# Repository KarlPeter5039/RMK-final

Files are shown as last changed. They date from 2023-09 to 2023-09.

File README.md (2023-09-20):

# RMK-final
Final iteration of the Reconfigurable Mechanical Keyboard including firmware and PCB files

Developed at Lehigh University for ECE 258 by Sumin Lim '23 and Karl Peter '23

Final PCB render

# Abstract
This project aims to explore new and innovative approaches to keyboard design, with a focus on improving user experience by integrating a modular configuration that can be flexible with user needs. The report begins by introducing our initial design, functionality, and how it improves. Communication between modules is made possible by I2C via TRRS jacks. The report then discusses the development process of this project. This includes hardware and software specifications, ethical aspects, altercations that were made, and discussion of the final design. The last section of this report explores future work or adjustments that could be made to further enhance this project. Overall, this project report demonstrates the value of innovative approaches to keyboard design and highlights the potential for future developments in this field.

Function Block Diagram

# Introduction
Anyone can go out and buy a keyboard, but most are fixed designs/sizes and lack functions that are desirable to those who need them. With a modular configuration, a reconfigurable keyboard is all-in-one and can scale up or down, depending on the task, at any time. This is achieved through a magnetic connection with detachable data pins between modules. The final project will include the following modules: left hand master, right hand, number row, function row, analog knob input cluster, slide potentiometer cluster, arrow key cluster with OLED display, and the number pad.

While there have been many designs for modular keyboards, nothing out there really comes close to the practicality of our design. It will be different from generic commercial designs by adding additional peripherals including rotary encoders for analog input, a fully modular set up, and dedicated keyboard portions that can be connected and disconnected at any time. 

Breakdown of inputs/outputs

# Technical Specifications
## Hardware Specifications:
- Elite-C Microcontrollers - ATmega32U4-based processor at 16MHz with 32KB of flash storage, 26 GPIO pins, and tactile reset button
- Diodes - To prevent back-currents in the keyboard matrix
- TRRS jacks - For I2C connection of modules carrying 4 wires
- Pull-up resistors - 4.7k ohm connected from VCC to SDA and SCL for I2C
- 128X32 OLED screen - Display for words per minute count and bongo cat
- Switches - Digital Cherry MX-based Switches
- Slide Potentiometer - Analog slide input for relative positioning input
- Rotary Encoders - Analog rotating potentiometer inputs for absolute positioning input
- Keyboard plate - 3D printed to mechanically support switches
- PCBs - Designed in KiCAD and ordered from JLCPCB

## Firmware Specifications:
The firmware for a keyboard consists of four primary files: 
- keymap.c: Defines the key mapping of the keyboard
- config.h: Defines the low-level configuration for the keyboard
- rules.mk: Defines the parameters of the ATMega32u4 controller 
- info.json: Defines the physical keyboard layout visually in JavaScript

QMK Firmware was used to configure the keymap, matrix with corresponding rows and columns, and assign keycodes for each of the switches on the keyboard. These files were then flashed to the microcontroller's memory.

### Required software
- QMK MSYS to compile the .c, .h, .mk. and .json files into a single hex file
- QMK Toolbox to flash the compiled hex file to the microcontroller over USB (lots of good tutorials on this)

PCB Schematic view

On the Arduino Pro Micro/Elite-C, I2C is supported through pins PD1, PD0, GND, and VCC (additional pull-up resistors were required). This connection can be achieved through two 4-pin TRRS jacks with a 3.5mm cable. Most of I2C communication lies in the keyboard firmware in the keymap file (.c), config header file (.h), and the rules file (.mk). The left hand module can function on its own, but without it, the rest of the modules would fail to operate.

Final PCB design

# Future Work
We chose to take a simplified approach to our original project plan due to potential hardware address limitations in QMK for 8 modules. We concluded that it would be better to have a couple working modules as opposed to 8 non-working ones. For our final keyboard, we cut the modules to just a left and right half but still included an OLED screen, digital switches, slide potentiometer, and rotary encoders. For future works, this keyboard can potentially expand to our initial goal of the 8 modules specified.

Additionally, to manufacture this keyboard on a larger scale, we have the following design altercations in mind: Breaking away from the Breakout Board, ISP (In-System Programming), Independent Molex/USB/Aviator connection, and LED indicators for boot status/flashing.

### Breaking away from the Breakout Board: 
It is far easier and cheaper to mass produce the PCB without the Arduino/Elite-C breakout boards that house the ATMega32U4 microprocessor. SMD components would be used with an on-board clock at 16MHz, capacitors for phase inversion, and bypass capacitors between Vcc and GND to reduce switching noise.

### ISP (In-System Programming): 
This allows quick flashing of the device with firmware without a direct USB connection. This is ideal in a factory environment where it’s impractical to plug each freshly soldered PCB with a USB connection. Instead, a 6 pin ISP connection will be mounted on the board for device access.
Independent Molex/USB/Aviator connection: This is required when eliminating the breakout board. D+ and D- data connections will be soldered to the connectors to further streamline production and reduce costs at a larger scale.

### LED indicators for boot status/flashing: 
A two LED setup will be used for when the keyboard’s memory is being wiped and when the keyboard is successfully and continuously connected with no errors. This will add two additional resistors for each LED.

Flashing the device

# Building your own RMK

## Bill of Materials (BOM)
| Component Name | Quantity |
| :---: |  :----:  |
| Elite-C Microcontrollers| 2x |
| 1N4148 Diodes | 63x |
| TRRS PJ-320A jacks | 2x |
| 4.7k resistors | 2x |
| 128x32 OLED screen | 1x | 
| 10k Slide Potentiometer | 1x |
| EC11 Rotary Encoders | 3x |
| Mechanical Switches | 63x |
| Left Keyboard Plate | 1x |
| Right Keyboard Plate | 1x |
| Keyboard PCB | 1x |

To order and build your own RMK, you'll have to source the above components on your own. Good keyboard part vendors include [Keebio](https://keeb.io/), [Aliexpress](https://www.aliexpress.com/), [DigiKey](https://www.digikey.com/), [Little Keyboards](https://www.littlekeyboards.com/), [Custom KBD](https://customkbd.com/), and [Amazon](https://www.amazon.com/ref=nav_logo).
Here, you can obtain most common items such as diodes, microcontrollers, TRRS jacks, and more.

For the PCB, download the PCB gerber and drill files from the repository and upload them to [JLCPCB](https://jlcpcb.com/) and order the 2-layer PCB (minimum order quantity should be around ~5 PCBs. Keyboard plates can be designed by hand or 3D printed if you're fancy.

To build the keyboard: a good approach is to first flash the microcontrollers with firmware to test their functionality and return them if they do not work. After that, solder components while periodically testing the board for functionality (shorting key pins with diodes, turning the rotary encoders, sliding the analog slider, etc.). Hopefully, after some sweat and hopefully no tears, you'll have your own working RMK! Firmware can additionally be customized to your liking by editting the various provided files and compiling them using QMK MSYS + flashing with QMK Toolbox. 

Customization includes 
- Custom keymaps
- Custom rotary encoder functions
- Custom OLED image/animation/information display
- Special macro keys
- Additional layers
- Mapping of analog slider
- Endless possibilities (possibly)

# Acknowledgements
Thank you to Professor Khazaei, Professor Cutitaru, Professor Norian, Ted Bowen, Xiyuan, and Kelly Zona for their help, feedback, and guidance for this project throughout the course of the year.

Additional render

This is a completed project with no intentions to add or revise. If you have any questions or comments, you can reach me at karlpeteryu@gmail.com

Keyboard layout in use

# References
“Designing F13 WKL Tkl Keyboard in Fusion 360”, Zlane - YouTube.com
https://www.youtube.com/watch?v=pvVdCHGJLY4

“A modern handwiring guide - stronger, cleaner, easier”, cribbit - geekhack.com
https://geekhack.org/index.php?topic=87689.0

“Building a Split Keyboard part 2”, Mark Story - mark-story.com
https://mark-story.com/posts/view/building-a-split-keyboard-part-2

“Rotary Encoder + Button Keyboard Output (Arduino Pro Micro)”, dkgrieshammer - Github
https://gist.github.com/dkgrieshammer/66cce6ec92a6427c16804df84c22cc83

“Adding SSD1306 OLED display to your build”, u/ishtob - Reddit
https://www.reddit.com/r/olkb/comments/5zy7og/adding_ssd1306_oled_display_to_your_build/

“Pheromone Keyboard”, luantty2 - Github
https://github.com/luantty2/pheromone_keyboard

“I2C Wiring for Splits”, u/VexillaVexme - Reddit
https://www.reddit.com/r/ErgoMechKeyboards/comments/k4x0a7/i2c_wiring_for_splits/

“A Complete Guide to Building a Hand-Wired Keyboard”, Ben Chapman - crackedthecode.com
https://www.crackedthecode.co/a-complete-guide-to-building-a-hand-wired-keyboard/#hardware-needed

“QMK Feature Options”, QMK group - docs.qmk.fm
https://docs.qmk.fm/#/config_options?id=feature-options

“Lily58 project”, F_YUUCHI - Ortholinear column-staggeredの分割キーボード
https://kata0510.github.io/Lily58-Document/

“Litl keyboard”, mohoyt - Github
https://github.com/mohoyt/litl

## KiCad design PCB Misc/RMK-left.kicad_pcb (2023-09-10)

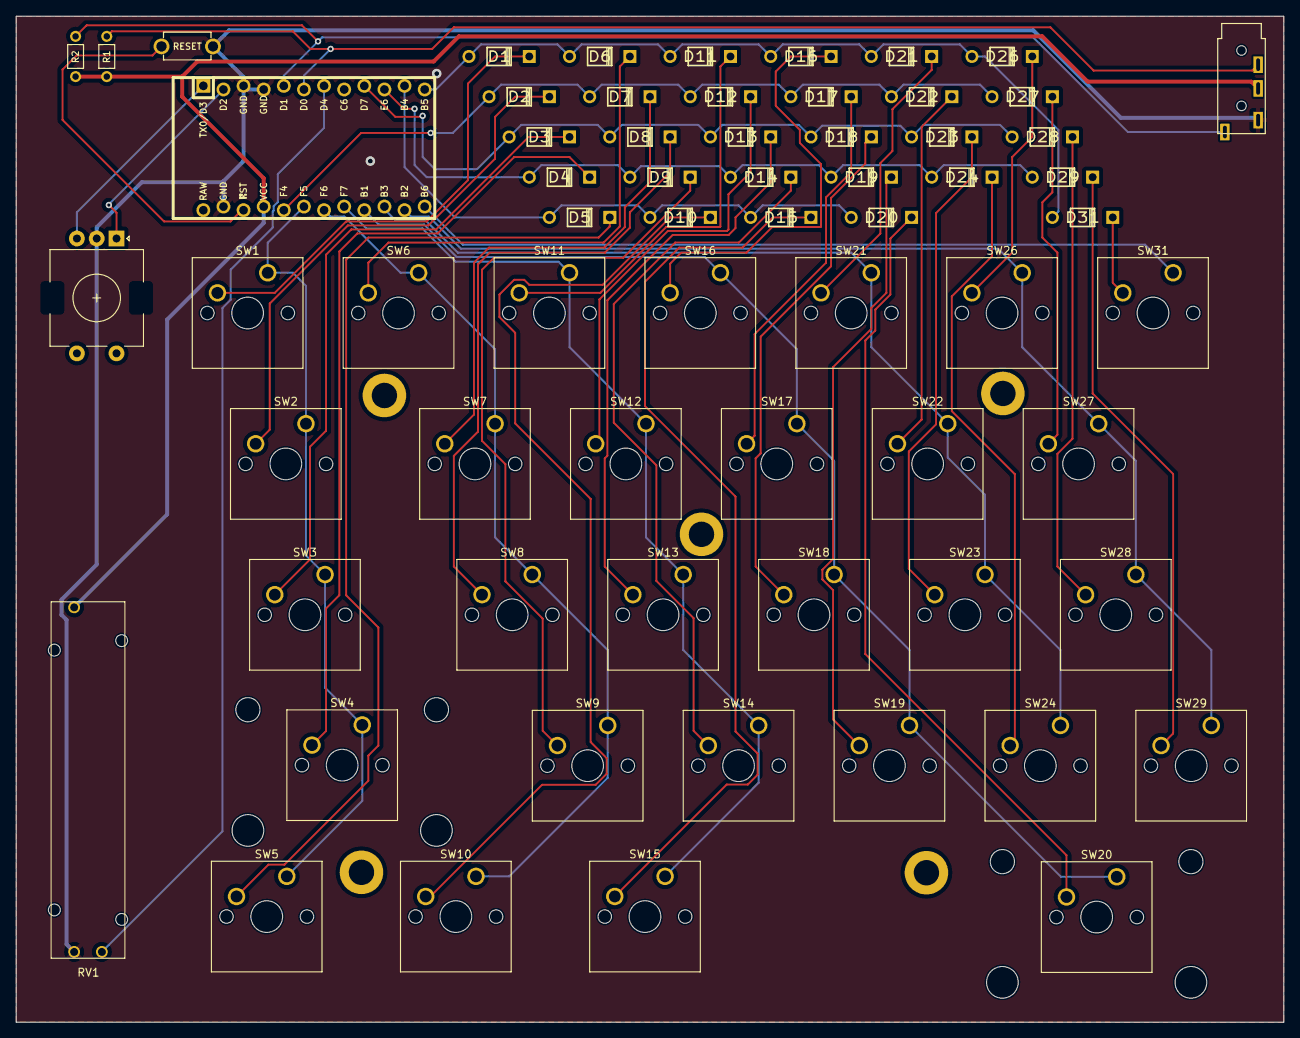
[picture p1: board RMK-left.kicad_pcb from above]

Board: 2 copper layers, 160.0 x 127.0 mm, 65 parts (1 on the bottom side), 49 nets.

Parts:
D1, D2, D3, D4, D5, D6, D7, D8, D9, D10, D11, D12, D13, D14, D15, D16, D17, D18, D19, D20, D21, D22, D23, D24, D26, D27, D28, D29, D31: D_Small; Diode
R1, R2: 4.7k; RESISTOR
ROT1: RotaryEncoder; RotaryEncoder_EC11
RV1: R_Potentiometer; potentiometer_slider_45mm
SW1, SW6, SW7, SW8, SW9, SW11, SW12, SW13, SW14, SW16, SW17, SW18, SW19, SW21, SW22, SW23, SW24, SW26, SW27, SW28, SW29, SW31: KEYSW; SW_Cherry_MX_1.00u_PCB
SW2: KEYSW; SW_Cherry_MX_1.50u_PCB
SW3: KEYSW; SW_Cherry_MX_1.75u_PCB
SW4, SW20: KEYSW; SW_Cherry_MX_2.25u_PCB
SW5, SW10, SW15: KEYSW; SW_Cherry_MX_1.25u_PCB
SW_A1: SW_PUSH; TACT_SWITCH_TVBP06
U1: ProMicro; ArduinoProMicro-ZigZag
U2: 4PIN; TRRS

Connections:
GND: ROT1.C, RV1.1, SW_A1.2, U1.3 (GND), U1.4 (GND), U1.23 (GND), U2.1 (SLEEVE)
unnamed: D1.2 (A), SW1.2
unnamed: D2.2 (A), SW2.2
unnamed: D3.2 (A), SW3.2
unnamed: D4.2 (A), SW4.2
unnamed: D5.2 (A), SW5.2
unnamed: D6.2 (A), SW6.2
unnamed: D7.2 (A), SW7.2
unnamed: D8.2 (A), SW8.2
unnamed: D9.2 (A), SW9.2
unnamed: D10.2 (A), SW10.2
unnamed: D11.2 (A), SW11.2
unnamed: D12.2 (A), SW12.2
unnamed: D13.2 (A), SW13.2
unnamed: D14.2 (A), SW14.2
unnamed: D15.2 (A), SW15.2
unnamed: D16.2 (A), SW16.2
unnamed: D17.2 (A), SW17.2
unnamed: D18.2 (A), SW18.2
unnamed: D19.2 (A), SW19.2
unnamed: D20.2 (A), SW20.2
unnamed: D21.2 (A), SW21.2
unnamed: D22.2 (A), SW22.2
unnamed: D23.2 (A), SW23.2
unnamed: D24.2 (A), SW24.2
unnamed: D26.2 (A), SW26.2
unnamed: D27.2 (A), SW27.2
unnamed: D28.2 (A), SW28.2
unnamed: D29.2 (A), SW29.2
unnamed: D31.2 (A), SW31.2
SCL: R1.2, U1.6 (3/PD0), U2.3 (RING1)
SDA: R2.2, U1.5 (2/PD1), U2.4 (RING2)
VCC: R1.1, R2.1, RV1.3, U1.21 (VCC), U2.2 (TIP)
col1: SW1.1, SW2.1, SW3.1, SW4.1, SW5.1, U1.19 (A2/PF5)
col2: SW6.1, SW7.1, SW8.1, SW9.1, SW10.1, U1.18 (A1/PF6)
col3: SW11.1, SW12.1, SW13.1, SW14.1, SW15.1, U1.17 (A0/PF7)
col4: SW16.1, SW17.1, SW18.1, SW19.1, SW20.1, U1.16 (15/PB1)
col5: SW21.1, SW22.1, SW23.1, SW24.1, U1.15 (14/PB3)
col6: SW26.1, SW27.1, SW28.1, SW29.1, U1.14 (16/PB2)
col7: SW31.1, U1.13 (10/PB6)
encA: ROT1.B, U1.1 (TX0/PD3)
encB: ROT1.A, U1.2 (RX1/PD2)
reset: SW_A1.1, U1.22 (RST)
rowA: D2.1 (K), D7.1 (K), D12.1 (K), D17.1 (K), D22.1 (K), D27.1 (K), U1.20 (A3/PF4)
rowB: D3.1 (K), D8.1 (K), D13.1 (K), D18.1 (K), D23.1 (K), D28.1 (K), U1.9 (6/PD7)
rowC: D4.1 (K), D9.1 (K), D14.1 (K), D19.1 (K), D24.1 (K), D29.1 (K), U1.10 (7/PE6)
rowD: D5.1 (K), D10.1 (K), D15.1 (K), D20.1 (K), U1.11 (8/PB4)
rowE: D1.1 (K), D6.1 (K), D11.1 (K), D16.1 (K), D21.1 (K), D26.1 (K), D31.1 (K), U1.12 (9/PB5)
slidePot: RV1.2, U1.7 (4/PD4)

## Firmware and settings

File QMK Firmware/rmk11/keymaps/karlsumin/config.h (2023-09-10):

/*
This is the c configuration file for the keymap

Copyright 2012 Jun Wako <wakojun@gmail.com>

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
You should have received a copy of the GNU General Public License
along with this program.  If not, see <http://www.gnu.org/licenses/>.
*/

#ifndef CONFIG_USER_H
#define CONFIG_USER_H

#define NO_ACTION_TAPPING
#define NO_ACTION_ONESHOT

#include "include.h"

/* Rotary Encoder */
#define ENCODERS_PAD_A { D3 }
#define ENCODERS_PAD_B { D2 }
#define ENCODER_RESOLUTION 4
#define ENCODERS_PAD_A_RIGHT { D3 , D4 }
#define ENCODERS_PAD_B_RIGHT { D2 , C6 }
#define ENCODER_RESOLUTION_RIGHT 4 

#define MIDI_ADVANCED
#define SLIDER_PINA D4

/* Select hand configuration */
#define MASTER_LEFT
// #define MASTER_RIGHT
// #define EE_HANDS

#define SPLIT_WPM_ENABLE
#define USE_I2C
#define SPLIT_OLED_ENABLE

#endif

#ifndef NO_DEBUG
#define NO_DEBUG
#endif // !NO_DEBUG
#if !defined(NO_PRINT) && !defined(CONSOLE_ENABLE)
#define NO_PRINT
#endif // !NO_PRINT

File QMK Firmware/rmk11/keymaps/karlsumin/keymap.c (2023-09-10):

#include QMK_KEYBOARD_H
#include <stdio.h>



bool is_alt_tab_active = false;
uint16_t alt_tab_timer = 0;

bool encoder_update_user(uint8_t index, bool clockwise) {

/* First encoder */
  if (index == 0) { 
    if (clockwise) {
      tap_code(KC_PGUP);
    } else {
      tap_code(KC_PGDN);
    }

/* Second encoder */
  } else if (index == 1) { 
    if (clockwise) {
      tap_code(KC_VOLD);
    } else {
      tap_code(KC_VOLU);
    }

/* Second encoder */
  } else if (index == 2) { 
    if (clockwise) {
      if (!is_alt_tab_active) {
        is_alt_tab_active = true;
        register_code(KC_LALT);
      }
    alt_tab_timer = timer_read();
    tap_code16(S(KC_TAB));

  } else {
    if (!is_alt_tab_active) {
      is_alt_tab_active = true;
      register_code(KC_LALT);
    }
    alt_tab_timer = timer_read();
    tap_code16(KC_TAB);
    }  	
  }
  return false;
}



#include "analog.h"
#include "midi.h"

extern MidiDevice midi_device;

int16_t pot_oldVal = 0;
int16_t pot_val    = 0;
int16_t pot_ccVal  = 0;

void matrix_scan_user(void) {

if (is_alt_tab_active) {
    if (timer_elapsed(alt_tab_timer) > 1250) {
      unregister_code(KC_LALT);
      is_alt_tab_active = false;
    }
  }

pot_val = (analogReadPin(D4));
pot_ccVal = pot_val / 8;
    
if (abs(pot_val - pot_oldVal) > 12) {
        pot_oldVal = pot_val;
        midi_send_cc(&midi_device, 0, 27, pot_ccVal);
    }
}



extern keymap_config_t keymap_config;

// #define _QWERTY 0
#define _FN 1

enum layer_names {
    _QWERTY,
};

enum custom_keycodes {
    QMKBEST = SAFE_RANGE,
    QWERTY = SAFE_RANGE,
    FN,
};

bool process_record_user(uint16_t keycode, keyrecord_t *record) {
    switch (keycode) {
    case QMKBEST:
        if (record->event.pressed) {
            // when keycode QMKBEST is pressed
            SEND_STRING("TOP DIFF");
	    SEND_STRING(SS_TAP(X_ENTER));
        } else {
            // when keycode QMKBEST is released
        }
        break;
    }
    return true;
};

const uint16_t PROGMEM keymaps[][MATRIX_ROWS][MATRIX_COLS] = {
    [_QWERTY] = LAYOUT(
	KC_ESC,  KC_1,    KC_2,    KC_3,    KC_4,    KC_5,    KC_6,    KC_7,    KC_8,    KC_9,    KC_0,    KC_MINS, KC_EQL,  KC_BSPC,
	KC_TAB,  KC_Q,    KC_W,    KC_E,    KC_R,    KC_T,    	       KC_Y,    KC_U,    KC_I,    KC_O,    KC_P,    KC_LBRC, KC_RBRC,
	KC_CAPS, KC_A,    KC_S,    KC_D,    KC_F,    KC_G,             KC_H,    KC_J,    KC_K,    KC_L,    KC_SCLN, KC_QUOT, KC_ENT,
        KC_LSFT, KC_Z,    KC_X,    KC_C,    KC_V,    KC_B,             KC_N,    KC_M,    KC_COMM, KC_DOT,  KC_SLSH, KC_UP,   QMKBEST,
        KC_LCTL, KC_LGUI, KC_LALT, KC_SPC,                             KC_SPC,  MO(_FN), KC_LEFT, KC_DOWN, KC_RIGHT, KC_NO, KC_BSLS
    ),

    [_FN] = LAYOUT(
	KC_GRAVE,KC_F1,   KC_F2,   KC_F3,   KC_F4,   KC_F5,   KC_F6,   KC_F7,   KC_F8,   KC_F9,   KC_F10,  KC_F11,  KC_F12,  KC_BSPC,
	  _______,   _______,   _______,   _______,   _______,   _______,            _______,   _______,   _______,   _______,   _______,   _______,   _______, 
          _______,   _______,   _______,   _______,   _______,   _______,            _______,   _______,   _______,   _______,   _______,   _______,   _______,
	  _______,   _______,   _______,   _______,   _______,   _______,            _______,   _______,   _______,   _______,   _______,   _______,   _______,
	  _______,   _______,   _______,   _______,                              _______,   _______,   _______,   _______,   _______,   _______, XXXXXXX
    )

};



// OLED setup for bongocat
#define IDLE_FRAMES 5
#define IDLE_SPEED 30
#define TAP_FRAMES 2
#define TAP_SPEED 40
#define ANIM_FRAME_DURATION 200
#define ANIM_SIZE 512

static long int oled_timeout = 600000; // 10 minutes
bool gui_on = true;
char wpm_str[10];
uint32_t anim_timer = 0;
uint32_t anim_sleep = 0;
uint8_t current_idle_frame = 0;
uint8_t current_tap_frame = 0;

//OLED stuff here
#ifdef OLED_ENABLE

static void render_anim(void) {

    // Idle animation
    static const char PROGMEM idle[IDLE_FRAMES][ANIM_SIZE] = {

        {
            0,0,0,0,0,0,0,0,0,0,0,0,0,0,0,0,0,0,0,0,0,0,0,0,0,0,0,0,0,0,0,0,0,0,0,0,0,0,0,0,0,0,0,0,0,0,0,0,0,0,0,0,0,0,0,0,0,0,128,64,64,32,32,32,32,16,16,16,16,16,8,8,4,4,4,8,48,64,128,0,0,0,0,0,0,0,0,0,0,0,0,0,0,0,0,0,0,0,0,0,0,0,0,0,0,0,0,0,0,0,0,0,0,0,0,0,0,0,0,0,0,0,0,0,0,128,128,128,0,0,0,0,0,0,0,0,0,0,0,0,0,0,0,0,0,0,0,0,0,0,0,0,0,0,0,0,0,0,0,0,0,0,0,0,0,0,0,0,0,0,0,0,0,0,0,0,0,24,100,130,2,2,2,2,2,1,0,0,0,0,128,128,0,0,0,0,0,0,0,0,0,128,0,48,48,0,192,193,193,194,4,8,16,32,64,128,0,0,0,128,128,128,128,64,64,
            64,64,32,32,32,32,16,16,16,16,8,8,8,8,8,4,4,4,4,4,2,2,2,2,1,1,1,1,0,0,0,0,0,0,0,0,0,0,0,0,0,0,0,0,0,0,0,0,0,0,0,0,0,0,0,0,0,0,0,0,0,0,0,0,0,0,0,0,0,0,0,0,0,0,0,0,0,0,0,192,56,4,3,0,0,0,0,0,0,0,12,12,12,13,1,0,64,160,33,34,18,17,17,17,9,8,8,8,8,4,4,8,8,16,16,16,16,16,17,15,1,1,0,0,0,0,0,0,0,0,0,0,0,0,0,0,0,0,0,0,0,0,0,0,0,0,0,0,0,0,0,0,0,0,0,0,0,0,0,0,0,0,0,0,0,0,0,0,0,0,0,0,0,0,0,0,128,128,128,128,128,64,64,64,64,64,32,32,32,32,32,16,16,16,16,16,8,8,8,8,8,4,4,4,4,4,2,3,2,2,1,1,1,1,1,1,2,2,4,4,8,8,8,8,8,7,
            0,0,0,0,0,0,0,0,0,0,0,0,0,0,0,0,0,0,0,0,0,0,0,0,0,0,0,0,0,0,0,0,0,0,0,0,0,0,0,0,0,0,0,0,0,0,0,0,0,0,0,0,0,0,0,0,0,0,0,0,0
        },

        {
            0,0,0,0,0,0,0,0,0,0,0,0,0,0,0,0,0,0,0,0,0,0,0,0,0,0,0,0,0,0,0,0,0,0,0,0,0,0,0,0,0,0,0,0,0,0,0,0,0,0,0,0,0,0,0,0,0,0,128,64,64,32,32,32,32,16,16,16,16,16,8,8,4,4,4,8,48,64,128,0,0,0,0,0,0,0,0,0,0,0,0,0,0,0,0,0,0,0,0,0,0,0,0,0,0,0,0,0,0,0,0,0,0,0,0,0,0,0,0,0,0,0,0,0,0,128,128,128,0,0,0,0,0,0,0,0,0,0,0,0,0,0,0,0,0,0,0,0,0,0,0,0,0,0,0,0,0,0,0,0,0,0,0,0,0,0,0,0,0,0,0,0,0,0,0,0,0,24,100,130,2,2,2,2,2,1,0,0,0,0,128,128,0,0,0,0,0,0,0,0,0,128,0,48,48,0,192,193,193,194,4,8,16,32,64,128,0,0,0,128,128,128,128,64,64,
            64,64,32,32,32,32,16,16,16,16,8,8,8,8,8,4,4,4,4,4,2,2,2,2,1,1,1,1,0,0,0,0,0,0,0,0,0,0,0,0,0,0,0,0,0,0,0,0,0,0,0,0,0,0,0,0,0,0,0,0,0,0,0,0,0,0,0,0,0,0,0,0,0,0,0,0,0,0,0,192,56,4,3,0,0,0,0,0,0,0,12,12,12,13,1,0,64,160,33,34,18,17,17,17,9,8,8,8,8,4,4,8,8,16,16,16,16,16,17,15,1,1,0,0,0,0,0,0,0,0,0,0,0,0,0,0,0,0,0,0,0,0,0,0,0,0,0,0,0,0,0,0,0,0,0,0,0,0,0,0,0,0,0,0,0,0,0,0,0,0,0,0,0,0,0,0,128,128,128,128,128,64,64,64,64,64,32,32,32,32,32,16,16,16,16,16,8,8,8,8,8,4,4,4,4,4,2,3,2,2,1,1,1,1,1,1,2,2,4,4,8,8,8,8,8,
            7,0,0,0,0,0,0,0,0,0,0,0,0,0,0,0,0,0,0,0,0,0,0,0,0,0,0,0,0,0,0,0,0,0,0,0,0,0,0,0,0,0,0,0,0,0,0,0,0,0,0,0,0,0,0,0,0,0,0,0,0,0
        },
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

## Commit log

2023-09-10 RMK Final Project
    Includes RMK firmware to be complied with QMK MSYS, all PCB files including gerbers and drill files, and partial lowprofile keyboard CHOC switch files
    [RMK-complete-B_Cu.gbr, RMK-complete-B_Mask.gbr, RMK-complete-B_Paste.gbr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]
2023-09-15 added bill of materials

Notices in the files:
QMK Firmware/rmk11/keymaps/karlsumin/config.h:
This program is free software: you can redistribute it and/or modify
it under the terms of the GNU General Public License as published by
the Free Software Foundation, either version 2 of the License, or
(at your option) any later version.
